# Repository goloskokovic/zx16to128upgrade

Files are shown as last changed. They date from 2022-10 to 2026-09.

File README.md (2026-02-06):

# 128k RAM expansion for the ZX Spectrum 48k

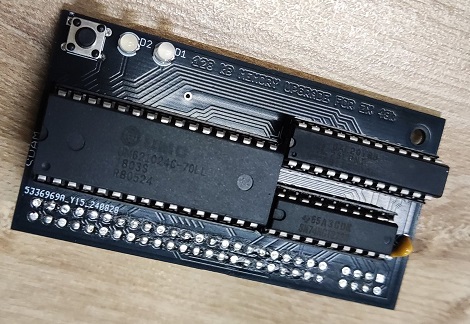
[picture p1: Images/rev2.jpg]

<br/>

Upgrade ZX Spectrum 48k with 128kB of RAM and play games you couldn't play before. Sound will stay as before, but you can always build an [AY interface](https://github.com/goloskokovic/zx16to128upgrade/tree/main/AY) to sound like ZX Spectrum 128k. No need to change the ROM.

In order to make the RAM expansion work, a single wire mod to your ZX Spectrum 48k is required to disable the 32k upper RAM.
For Issue 2/3/4 connect pin 5 on IC23 (74LS32) to pin 14 (+5V). For Issue 5/6 connect pin 35 on IC27 (ZX8401) to pin 40 (+5V).
Both mods will hold the CAS/RAS signal high so it won't reach the RAM chips.
<br/>

Watch the video:

Watch the video (https://www.youtube.com/watch?v=-c24jNaIezs&t=853s)

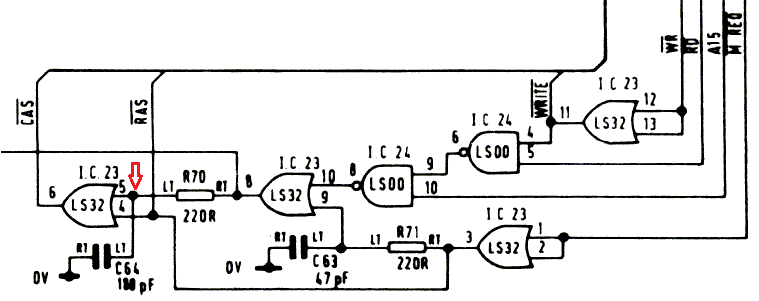
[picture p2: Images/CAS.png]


With this mod without the RAM expansion, your ZX Spectrum 48k will work as ZX Spectrum 16k.

To test the RAM expansion use modified [zx-diagnostics](/testram.tap) that allows you to manually select 128k test regardless of the ROM.

<br/>
<br/>
<br/>

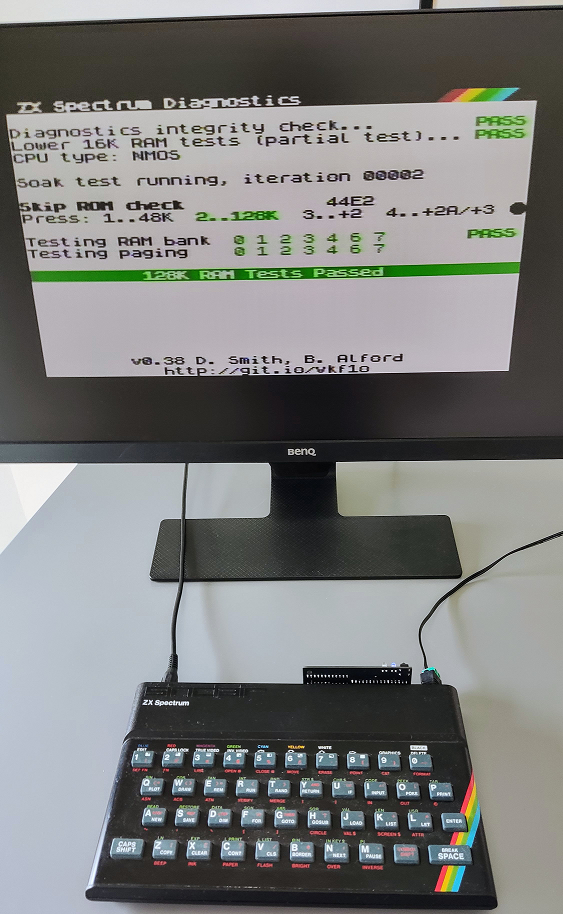
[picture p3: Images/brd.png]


<br/>
<br/>
GAL equations:

```
when 74HCT273_CLK is CLK7FFD
D0 is BANK0
D1 is BANK1
D2 is BANK2

CLK7FFD = /IORQ*/WR*/A15*A5*/A1
/RAMCS = /MREQ*A15
SA14 = A14*A15*BANK0
SA15 = A14*A15*BANK1 + /A14*A15
SA16 = A14*A15*BANK2
```
Original page: https://velesoft.speccy.cz/zx/external_128kb_upgrade/index.htm

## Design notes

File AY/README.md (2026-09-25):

# Simple AY interface

Part list:

1 x AY-3-8912

1 x 3.57954 MHz crystal

1 x 3,5mm jack socket PJ324

1 x 74LS138, 74LS00, 74LS74

2 x 1k resistor

2 x 1k6 resistor

5 x 470R resistor

2 x 100nF ceramic capacitor

2 x 4,7uF electrolytic capacitor

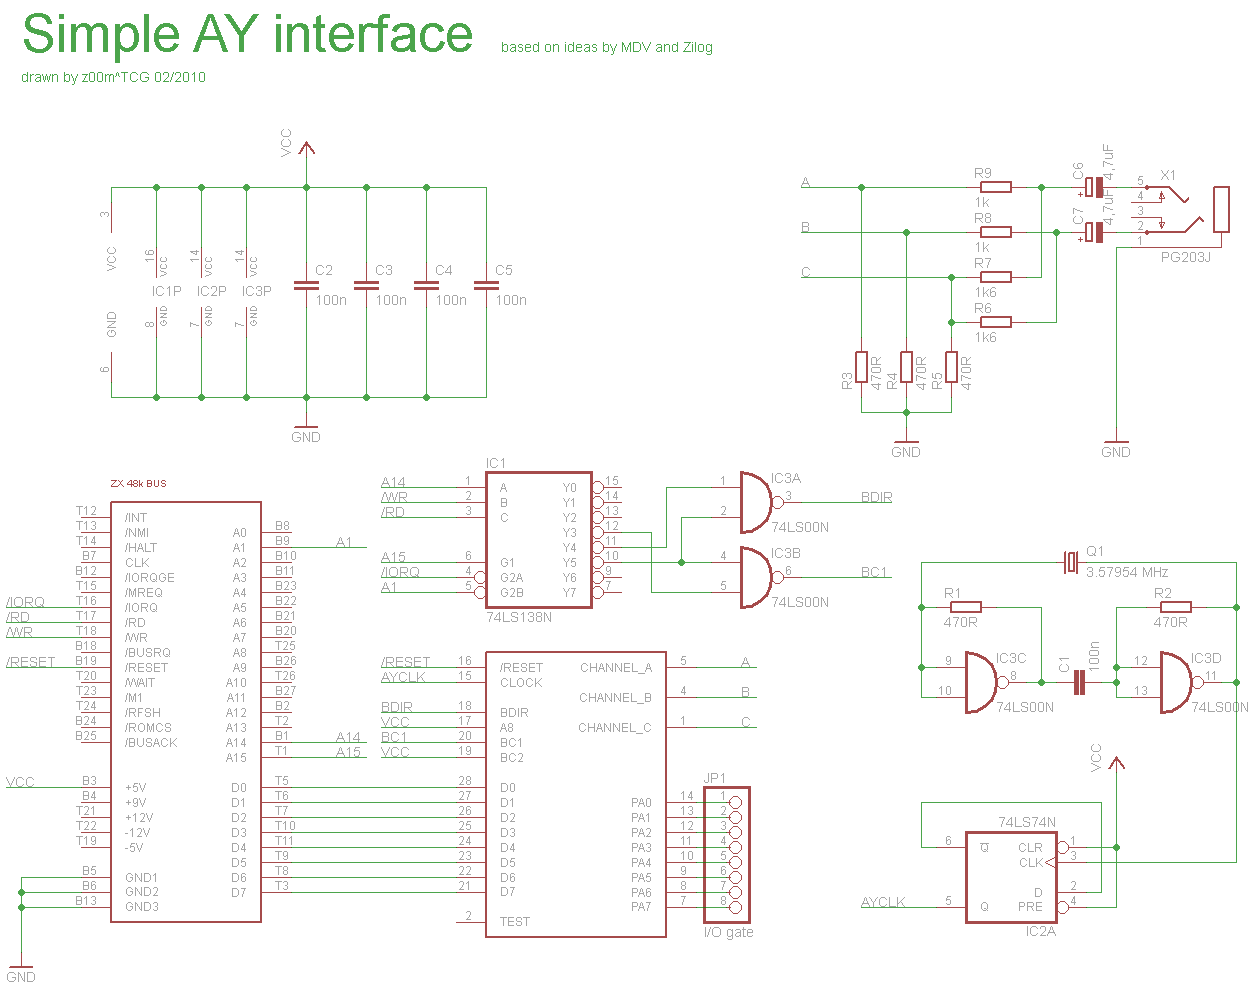
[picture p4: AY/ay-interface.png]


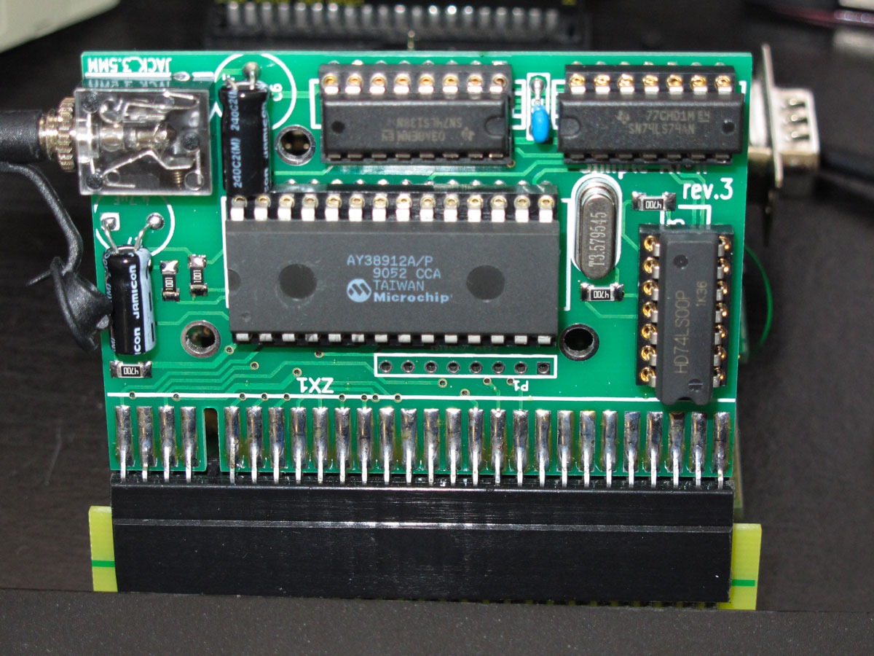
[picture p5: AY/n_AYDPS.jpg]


Original page:
https://www.zxsparrow.com/speccy_hw/simple/Simple_AY_IF/Simple_AY_IF_cze.html

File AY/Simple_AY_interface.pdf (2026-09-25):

# Návod na osazení Simple AY Interface rev.3

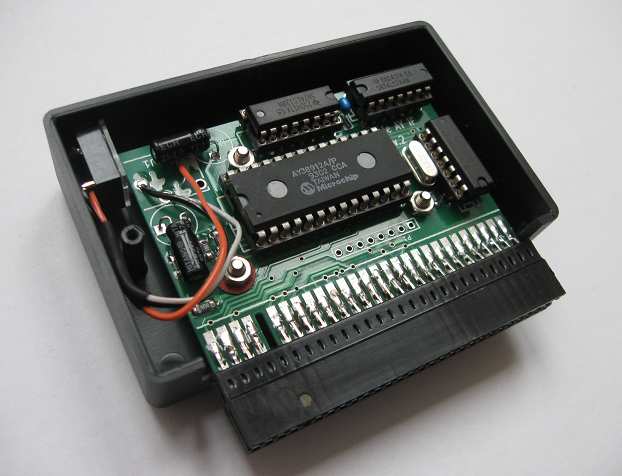
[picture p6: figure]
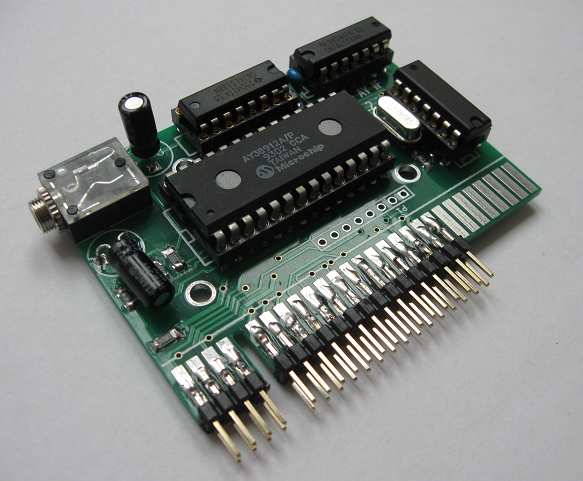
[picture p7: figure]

interface osazený přímým konektorem, v krabičce interface v provedení pro rozšiřující sběrnicovou desku ZX ExpBoard

## Součástky

kondenzátory
C1 | 100nF SMD1206
C2 | 100nF monolitický (GES05400223)
C6, C7 | 4,7uF elektrolytický

rezistory
R1, R2, R3, R4, R5 470R SMD1206
R6, R7 | 1k6 SMD1206
R8, R9 | 1k SMD1206

krystaly
X1 3.57954 MHz (GME 131-071)

integrované obvody
U1 | AY-3-8912
U2 | 74LS138 (GME 421-064)
U3 | 74LS00 (GES05000467)
U4 | 74LS74 (GES05000494)
+ precizní patice pro integrované obvody

konektory
J1 stereo jack 3.5mm (GME 809-028)
ZX1 přímý ZX konektor s klíčem, nebo dvouřadá pinová lišta pro ZX ExpBoard

krabička
KM26N (GES07203808), resp. U-KM26N (GME 622-341)
+ distanční sloupky výšky 6 nebo 8 mm se závitem M3, šroubky a matičky M3

## Postup

Před zahájením práce byste se měli rozhodnout, zda budete připojovat interface k počítači přímo (a tedy použijete klasický ZX konektor s klíčem), nebo prostřednictvím rozšiřující desky ZX ExpBoard (a použijete dvouřadou pinovou lištu).
Také se rozhodněte, zda budete interface zabudovávat do krabičky - pokud ne, můžete vynechat body 1 a 3.

## 1) Příprava krabičky

Pokud budete chtít zabudovat interface do krabičky, je vhodné si ji připravit k montáži ještě před osazením součástkami:

a) otočte desku na druhou stranu (než která má být v krabičce nahoře) a přiložte ji zvenčí ke krabičce tak, aby se okraj s konektorem kryl s okrajem krabičky; vzdálenost kratší hrany desky od okraje krabičky by na straně, kde je uvnitř montážní nálitek, měla být 13 mm:

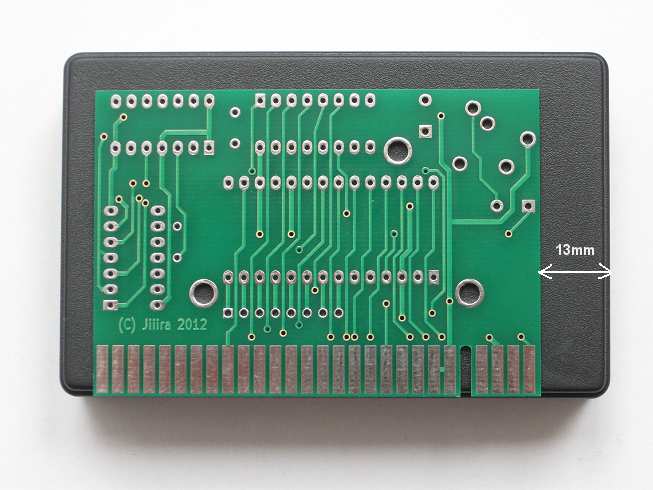
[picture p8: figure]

b) označte si umístění děr (rýsovací jehlou, bílým fixem...), desku sejměte a vyvrtejte montážní otvory vrtákem o průměru 3 mm :
c) vyřízněte otvor pro systémový konektor (nařízněte okraje pilkou a delší stranu nařízněte ostrým nožem a vylomte) a vyvrtejte otvor pro audio konektor, např. tak, jako je na následující fotografii (vzdálenost středu otvoru od kratší hrany krabičky min. 6 mm):

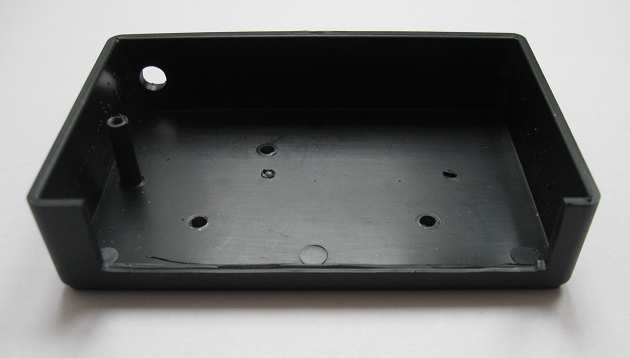
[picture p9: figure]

d) do připravené krabičky přišroubujte neosazenou desku a nepřipojený audio konektor, abyste se přesvědčili, že všechno „sedí“ a že např otvor pro systémový konektor je dostatečně velký. Upravte, co je třeba.

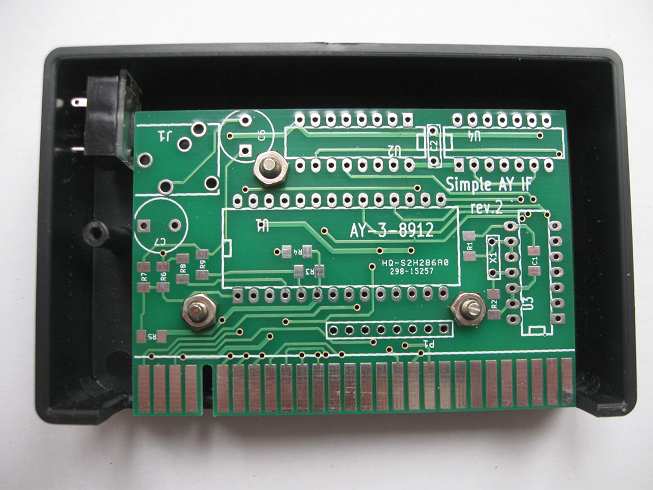
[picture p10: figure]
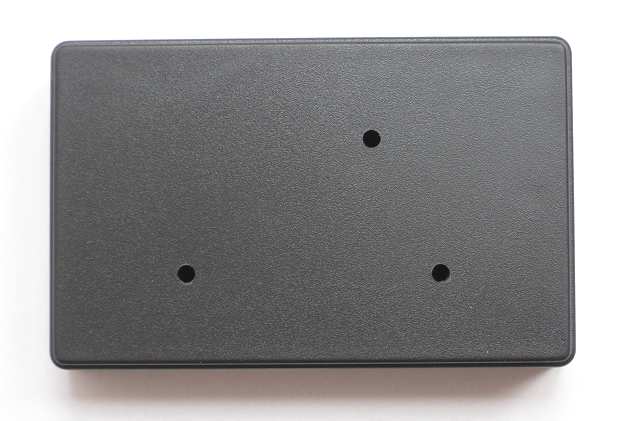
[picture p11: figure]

Když je vše v pořádku, vyšroubujte desku z krabičky a začněte s jejím osazováním.

## 2) Osazení desky součástkami

a) připájejte všechny SMD součástky (kondenzátor C1 a všechny rezistory)
b) připájejte systémový konektor - buď klasický přímý konektor s klíčem (pro připojení přímo k počítači ZX Spectrum), nebo dvouřadou pinovou lištu (pro připojení přes rozšiřovací desku ZX ExpBoard)

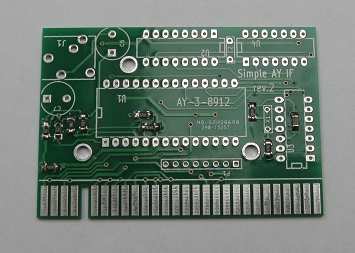
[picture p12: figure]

c) připájejte kondenzátory C2 a C7; připájejte všechny patice
d) u interface zabudovávaného do krabičky připájejte audio konektor pomocí drátků k odpovídajícím otvorům v desce; pokud nevestavujete interface do krabičky, zapájejte konektor přímo do desky
e) připájejte kondenzátor C6 a krystal X1

## 3) Montáž do krabičky

Pomocí distančních sloupků připevněte desku dovnitř krabičky; audio konektor zašroubujte do připraveného otvoru.

## 4) Vyzkoušení

Hotový interface zapojte do vypnutého počítače a zvukový výstup připojte do zesilovače. Zapněte počítač a vyzkoušejte funkci interface pomocí software podporujícího AY-8912, např. Fuxoft Soundtrack, SQ Tracker apod.). Pokud jste pracovali pečlivě, výsledek bude slyšitelný ;-)

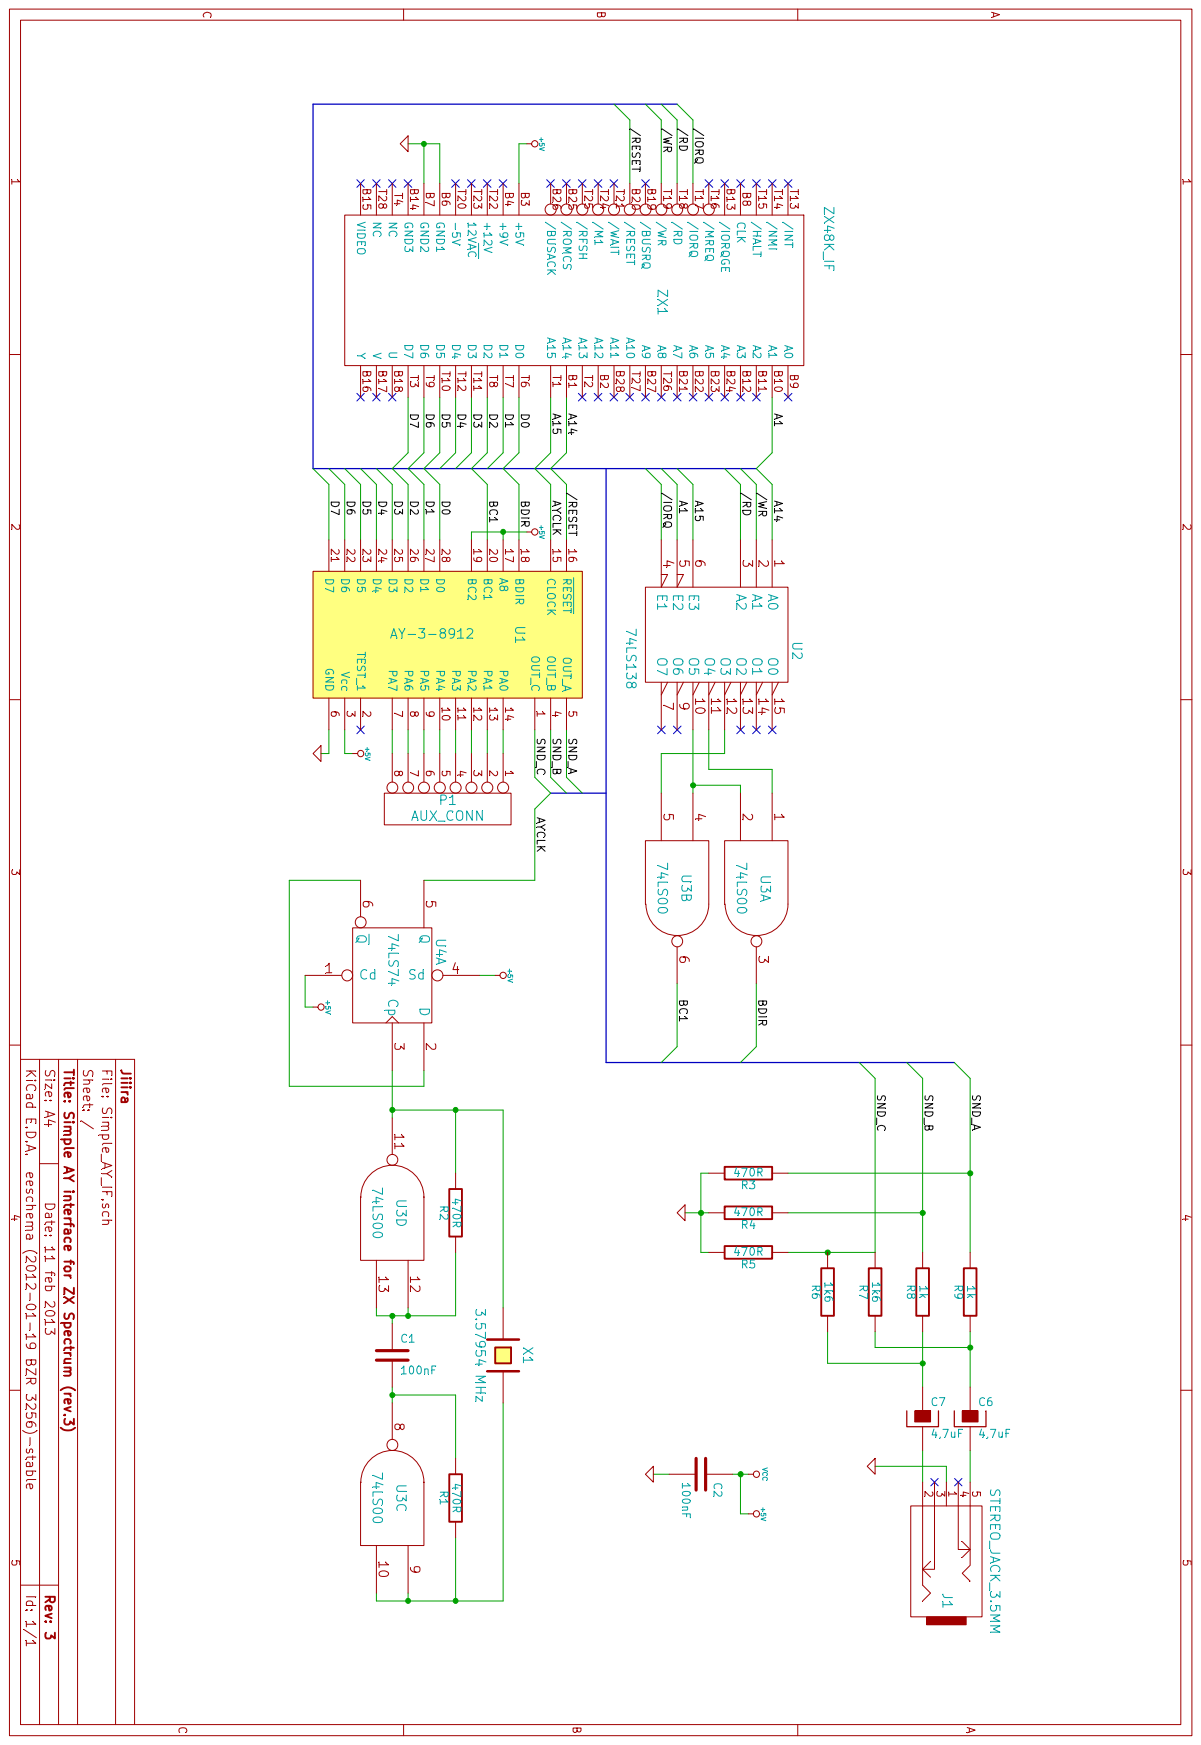
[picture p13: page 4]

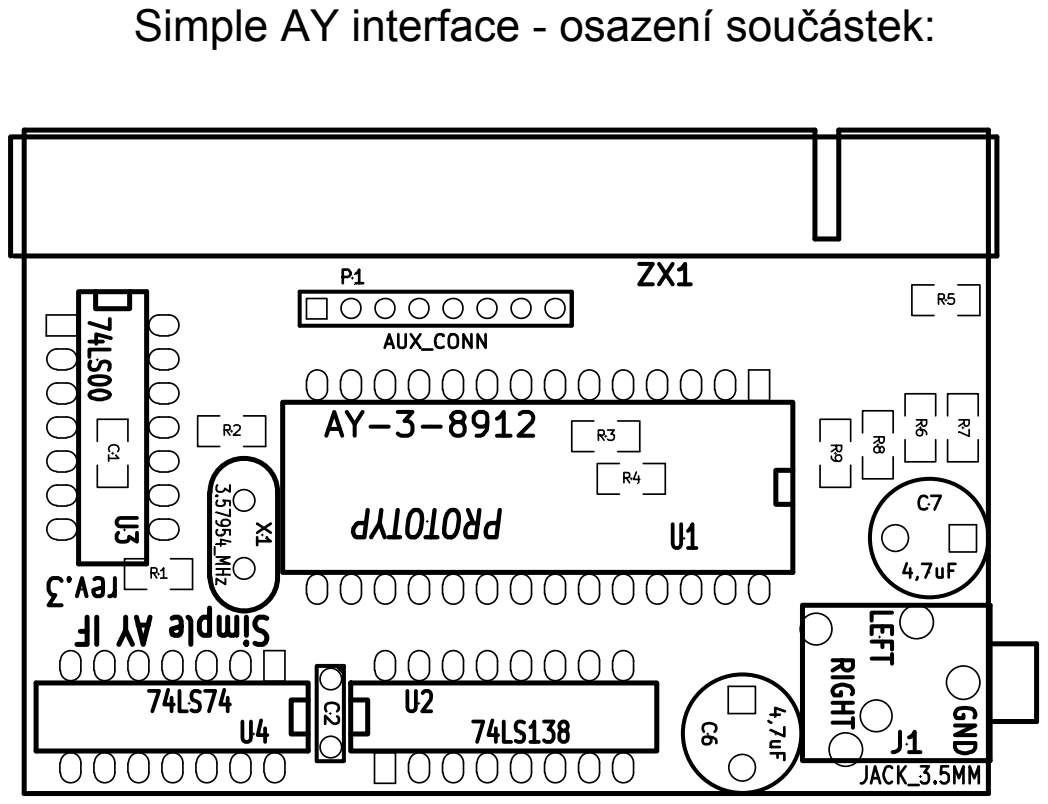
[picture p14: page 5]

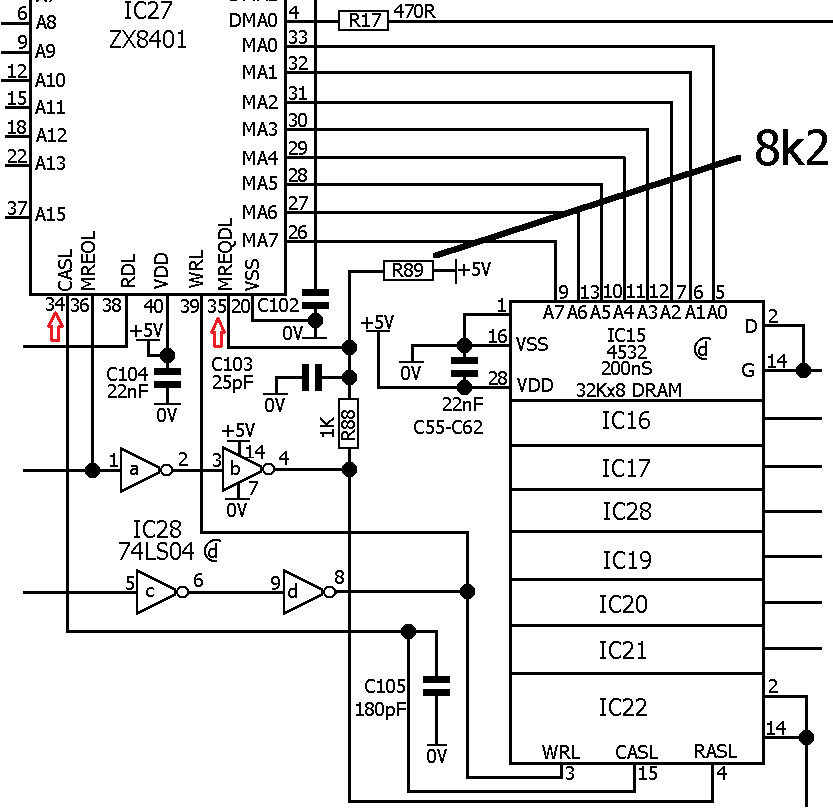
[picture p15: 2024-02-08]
Images/zx8401.png

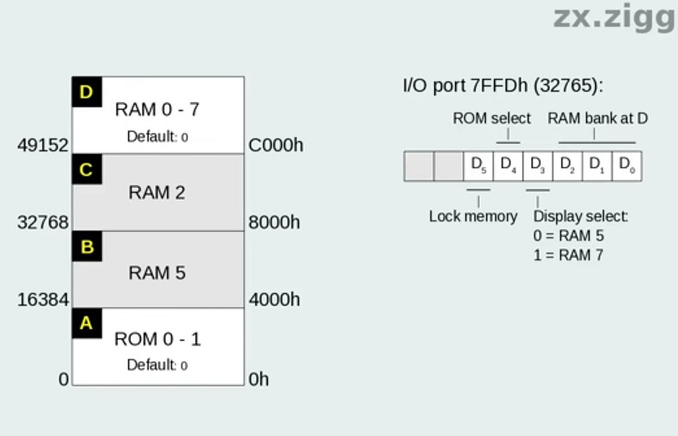
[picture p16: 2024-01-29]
Images/7FFDh.jpg

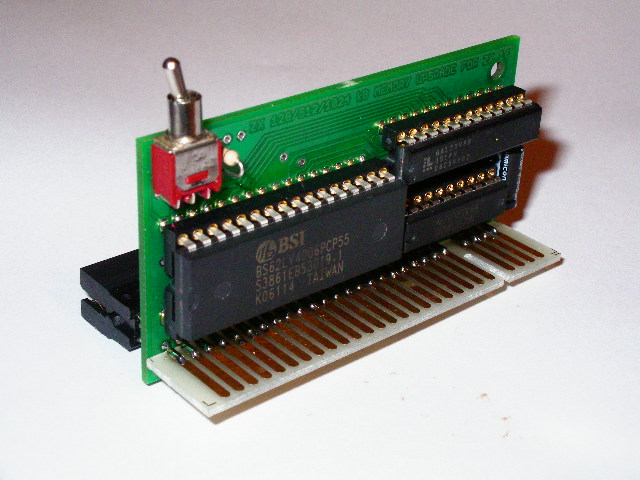
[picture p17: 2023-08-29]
Images/zx16to128upgrade7149.jpeg

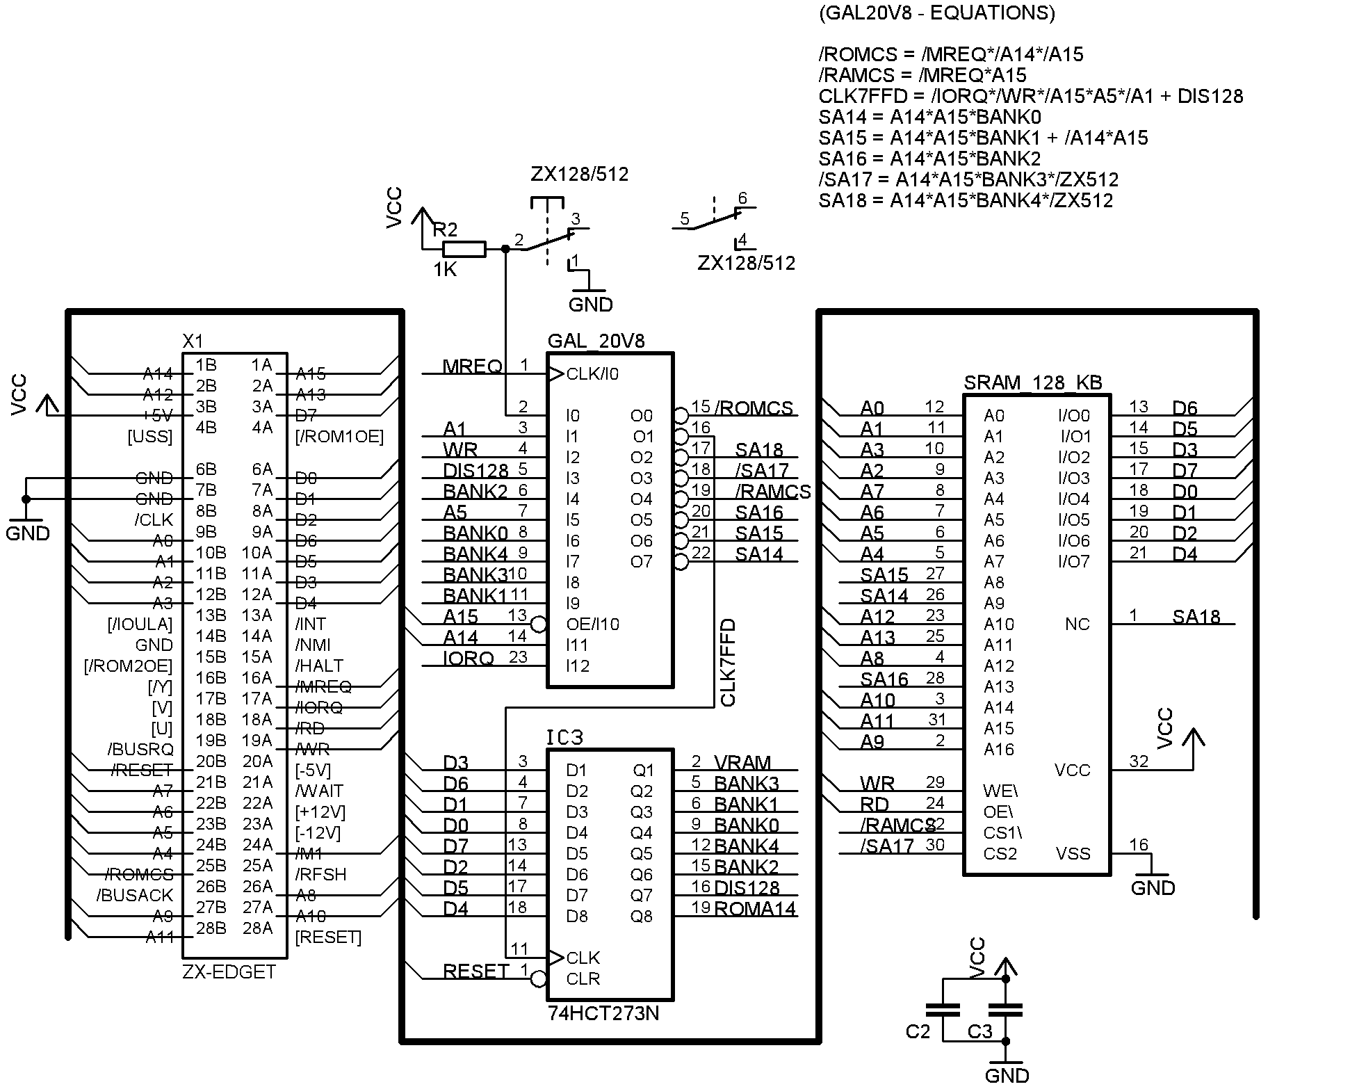
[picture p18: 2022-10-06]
Images/sch.png

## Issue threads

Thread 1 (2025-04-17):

Screen Ram Paging

robpearmain, 2025-04-17:
I did some testing, and although the 128k works, screen paging (Banks 5 and 7) don't

Is this due to the ROM, does it need upgrading to make screen paging work?

See here for the info, it might be because the ROM stores the last paging value:

https://worldofspectrum.org/faq/reference/128kreference.htm

goloskokovic, 2025-04-17:
what are you using for testing?

robpearmain, 2025-04-17:
I have a 16k spectrum and wanted to see if by adding the 128k ram it could
run all 128k games.  It can, but the page 5 and 7 screen memory swap
doesn’t work, but I think it is due to the ROM rather than the memory which
works fine

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

goloskokovic, 2025-04-17:
I believe you might be right. There is a version of this board with the rom, hence the rom cs line in GAL.
https://velesoft.speccy.cz/

robpearmain, 2025-04-18:
Also, on the original page (128k-512k) it clearly states (I missed this when I first posted).  “ D3 is unused (on real ZX128 machines select videoram 1/2). This upgrade can't support videoram switching. It is used only first videoram”.  I think this is because this is a function of the 128k ULA not available on the 16/48k ULA

goloskokovic, 2025-05-07:
https://cantinhotk90x.blogspot.com/2012/12/placas-da-tkmem-128-prontas.html

Closed 2025-04-18.

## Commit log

2023-07-17 add gerber files
2023-09-30 added AY pcbway project link
2023-10-04 pull up resistor comment
2024-03-09 reset switch
2024-04-14 new board
2024-06-16 ground plane
2024-06-30 gerbers folder
2024-07-02 one wire mod
2024-07-04 single wire mod
2024-09-13 v6c board
2026-02-03 bom update
2026-02-11 socket PJ324
